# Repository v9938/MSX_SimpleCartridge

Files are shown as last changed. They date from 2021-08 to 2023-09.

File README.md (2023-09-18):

# MSX用カートリッジ<BR>32/64K Simple ROM Cartridge
ひねりも何も無いFlash ROMを32/64KByteをマッピングしたカートリッジです。  
現在入手可能な部品を使い、最小現のパーツで構成されています。  

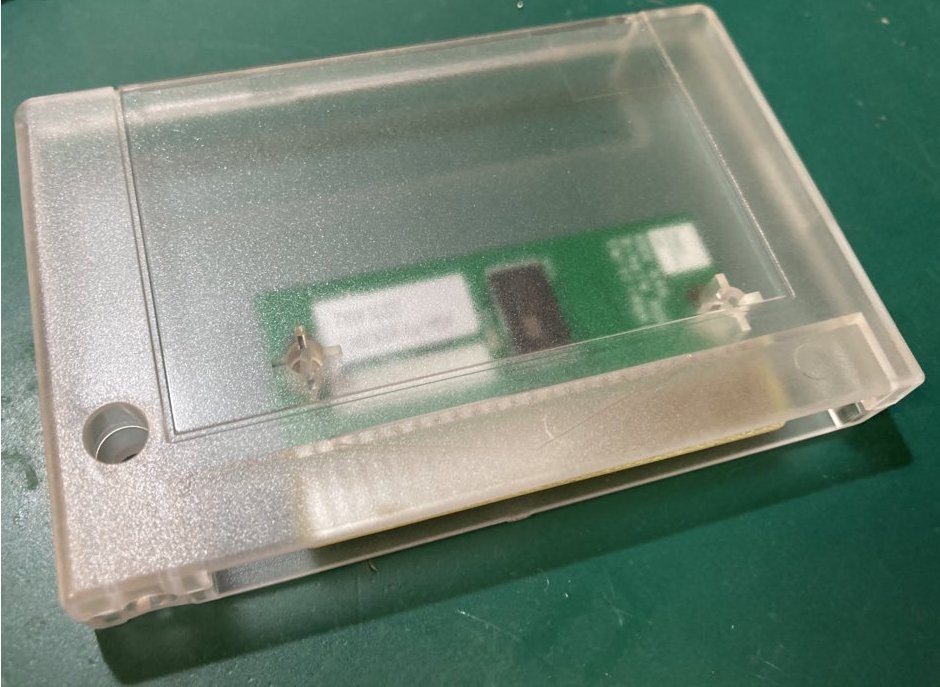
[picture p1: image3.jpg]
Case WithCase

  
SST社の39SF010/020/040との組み合わせで動作確認を行っていますが、  
基板自体はある程度汎用で利用できる様に設計されており、設定変更で他型番のEPROMの利用が可能です。  

なお、本基板および各パーツは、家電のKENちゃんおよびBoothにて頒布しています。  (Boothは不定期に追加)  

## ■ 頒布先
### 家電のKENちゃん
●MSX用カートリッジ64K Simple ROM Cartridge 【SOP版 完成品】  
https://www.kadenken.com/view/item/000000001288  

●シェルケース（廉価版）  
- クリアブラック  
https://www.kadenken.com/view/item/000000001497  
- クリアブルー  
https://www.kadenken.com/view/item/000000001498  
- クリアピンク  
https://www.kadenken.com/view/item/000000001500  
- クリアオレンジ  
https://www.kadenken.com/view/item/000000001499  
- 白  
https://www.kadenken.com/view/item/000000001496  
- 黒  
https://www.kadenken.com/view/item/000000001495  

シェルケース(RGR製)
- 透明  
https://www.kadenken.com/view/item/000000001315  

### Booth
●基板/パーツ/完成品  
-https://ifc.booth.pm/items/3200264
  
●カートリッジケース(RGR製)  
https://ifc.booth.pm/items/3240279

### JLCPCB
●シェルケース（3Dプリント）  
https://3d.jlcpcb.com/3d-models/detail/MX1901-MSX-Cartridge-shell-(KOMAMI-Type)

(2023/8/1追記)  
Microchip社のFlashROMのDIPパーケージ品が想定以上に値上がり&入荷が不安定なため、  
今後はSOP版 完成品のみの供給とさせていただきます。機能的な違いはありません。  
  
DIP版が必要な場合はガーバーファイルが同梱していますので、基板業者に直接注文してください。

## ■ Flashの制御方法
Flashのコントロールアドレス2AAAhは2AAAh・コントロールアドレス5555hは5555hにマッピングされています。  
  
本製品は、SST系のFlashを使用しています。  
CMD体系は、AMD系とほぼ同じなのですが、CMDアドレスが違います。  
また、BUSYの出方などもAMD系と異なるため注意してください。  

```
CMD例：
1. Flash Byte-Program 1st : 0x5555 = 0xAA
2. Flash Byte-Program 2nd : 0x2AAA = 0x55
3. Flash Byte-Program 3rd : 0x5555 = 0xA0
4. Write Data             : 0x0000～0xffff = data
```

参考：  
https://www.microchip.com/wwwproducts/en/SST39SF010A  

## ■ Flash書き込みプログラム
書き込みプログラムとして、simplefw.comを同梱しています。  
いずれかのスロットに当該カードリッジを挿入し、以下コマンドを実行してください。  
```
>simplefw.com [書き込みをしたいROM File]　(/0,4,8)
```
オプションとして下記が使えます  
/0 : ROMファイルを0x0000からのアドレスに書き込みます。  
/4 : ROMファイルを0x4000からのアドレスに書き込みます。  
/8 : ROMファイルを0x8000からのアドレスに書き込みます。  
  
書き込みのエンドアドレスは0xBFFFにしてあります。  
0xC000以降の書き込みが必要な場合は下記部分を変更して再コンパイルしてください。  
（0xFFFFは拡張スロットで使われるため書き込みできません）  
```
		//Parameter Check
		if (addressWrite >= 0xC000){				// 4000-Bfffh Write finsh?
			printf("\nROM size is FULL.");			// Ummm.ROM is FULL
```

スロット切り替えが面倒でBIOS Callで1Byteづつ処理しているので遅いです。ゆるして・・・  
  
ソースコードは、z88dkでコンパイル可能です。コンパイルオプションは下記になります。 
```
zcc +msx -create-app -subtype=msxdos -lmsxbios  main.c -o simplefw.com  
```
## ■ その他のFlash書き込みプログラムについて
HRA!氏作成のwrtsstで書き込み可能な事を確認しています。  
上記プログラムより書き込み速度が速いです。^^;  

●wrtsst
https://github.com/hra1129/MSX_MegaSCC_for_SST39SF040/tree/main/tools/wrtsst  

## ■ Flashで実行してるかを調べる方法
頒布用途で使用する場合、FlashROMのIDコードを読むことで、当カセットで実行しているか調べることが可能です。

TestProgram_ROMVerの下記関数を参照してください。  
(当該関数はROM上で実行することができないことに注意してください。)

```
int chkSimpleROM()
```
## ■ 頒布基板について（～RevCまで)
本製品は安価に頒布するため端子部はハンダメッキになっています。  
通常使用では問題は確認されていませんが、金メッキに比べると中長期的な信頼製や耐久性が劣ります。
あらかじめご了承ください。

頒布基板は組み立てキットの「DIP版」/完成品「SOP版」の2つのVersionがあります。  
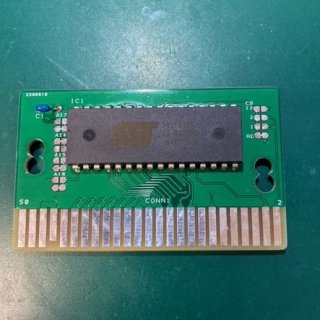
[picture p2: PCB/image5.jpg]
Dip
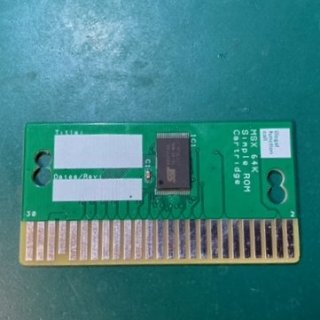
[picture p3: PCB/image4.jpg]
SOP
 

DIP版は32Kマッピング(64Kにも変更可能）SOP版は64Kマッピングの違いがあります。
  
| MSX Slot Address | Flash ROM Address(DIP版) | Flash ROM Address(SOP版) |
|---|---|---|
| 0000-3FFF | 0000-3FFF | 0000-3FFF |
| 4000-7FFF | 4000-7FFF | 4000-7FFF |
| 8000-BFFF | 0000-3FFF(mirror) | 8000-BFFF |
| C000-FFFF | 4000-7FFF(mirror) | C000-FFFF |

DIP版もA15ジャンパの設定変更でSOP版と同じメモリ配置にすることが可能です。

## ■ 頒布基板について（RevD以降)
金メッキ仕上げ品に変更になっているため上記問題はありません。  
メモリマッピングはSOP版と同じメモリ配置になっています。  
  
ガーバファイルを同梱していますので量産や仕様変更をされたい場合に利用ください。  

## ■ 頒布基板について（紫 基板SOP版)
金メッキ仕上げ品に変更しています。上記問題はありません。 
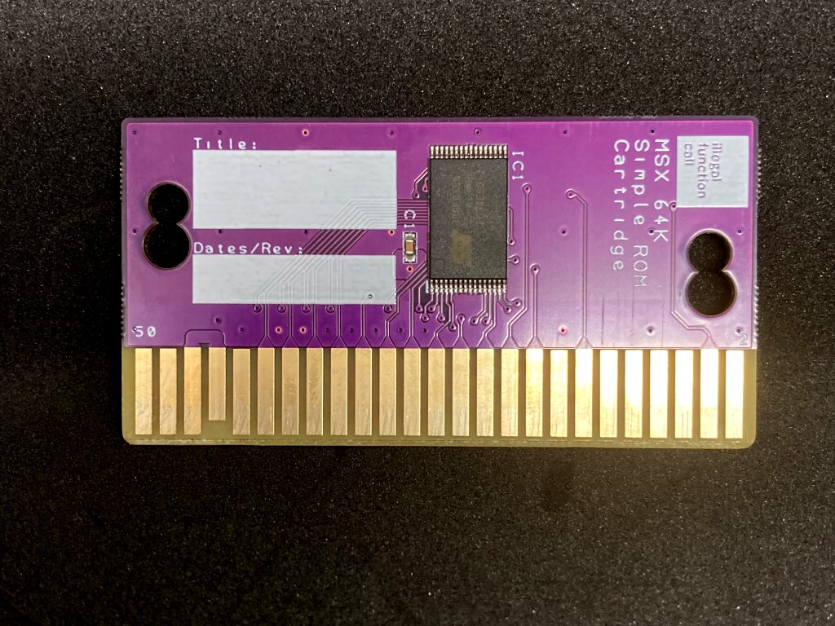
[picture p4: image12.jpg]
SOPPCB


動作確認用にROM IDを確認するソフトが書き込みしてあります。  
初回のみ"e"キーを押して内部のデータを消去してから使用してください。
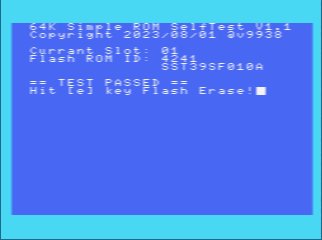
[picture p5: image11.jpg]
TESTDONE TestDone


## ■ ジャンパ設定について
組み立てキットの「DIP版」にはいくつかのジャンパが用意されています。  
設定を変更することにより、アドレス空間のマッピングや違う種類のEPROMを使う事が可能です。  
※Default値は、RevDの設定値(SST39SF010向け)になります、Revにより異なりますので注意ください。  

|ジャンパ  | A17(30Pin) | A14(29Pin) | A15(3Pin) | A18(1Pin) |
|---|---|---|---|---|
| 上側  | +5V  | A14(Default)  | A15(Default) | +5V |
| 下側  | GND(Default)  | A15  | GND  | GND(Default)  |

|CSジャンパ  | ROM ADDRESS |
|---|---|
| RD  | 0x0000-0xFFFF(Default) |
| CS1  | 0x4000-0x7FFF  |
| CS2  | 0x8000-0xBFFF  |
| CS12  | 0x4000-0x7FFF  |

## ■ EPROM設定例
|ジャンパ  | A17(30Pin) | A14(29Pin) | A15(3Pin) | A18(1Pin) |
|---|---|---|---|---|
| 27C32/64/128/256 | 上(+5V)  | 下(A15)  | 下(GND) or 両方カット＋+5Vへのジャンパ | 下(GND) |
| 27C010/040 | 下(GND)  | 下(GND)  | 下(GND)  | 上(+5V) |

### 27C32～256使用時の注意
VPPがGNDでも動作するROMの使用を想定しています。  
VPPに+5Vを要求するタイプの場合、A15に+5Vの選択がないためジャンパが必要です。  
A18上パッド左側が+5Vなので、A15パッドを両方カットし、右側にジャンパしてください。  
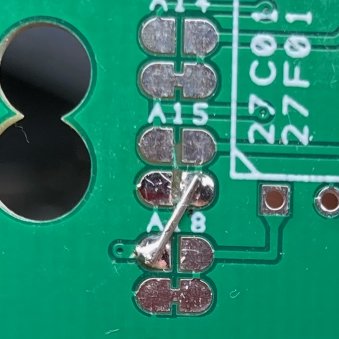
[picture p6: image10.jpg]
VPP対応
  

CSジャンパは、使用したいアドレス領域に合わせてCS1/2/12のいずれかを設定してください。  
27C256を使う場合はアドレスの配置が16KByteで反転するため、A14の設定も必ず変更する様にしてください。

## ■ 基板の組み立て方法
セオリー通り背の低い部品から半田付けしてください。IC1->C1が良いと思います。  
ICソケットを使うとケースに入らなくなるので注意してください。  

## ■ 部品表
| 部品番号 | 部品名 |
|---|---|
| IC1  | Flash ROM SST39SF010/020/040 |
| C1  | コンデンサー0.1uF (104) |
| PCB  | 専用PCB |

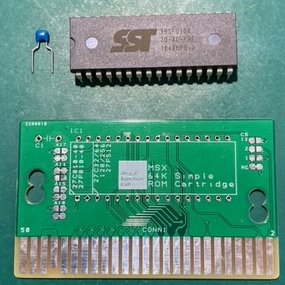
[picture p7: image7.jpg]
Parts


### ■ DIP版 RevBについて
A14 ジャンパのDefault設定が間違っています。下側のパターンをカットし、上側をショートさせてください。  
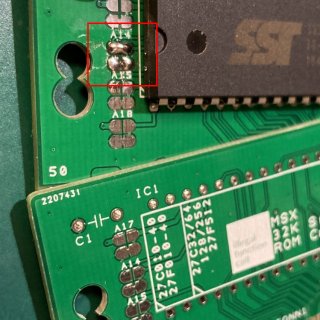
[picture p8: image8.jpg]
J_A14w
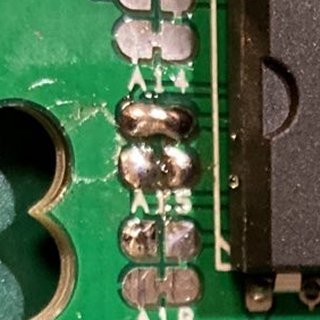
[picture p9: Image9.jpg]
J_A14
 

## ■ カードリッジシェルについて
コナミおよびASCIIタイプのシェルに合わせたネジ穴が空けてあります。  

### 3Dプリント用データ
3Dプリント用のSLTデータを同梱しています。  
固定ネジは2mm x 10mmのタッピングビスを使ってください。  
サンコータイト（＋）Ｐタイプナベに合わせて設計しています。  

JLC PCBさんの3Dプリント Shareデータに登録してあります。材質によりますが、価格は＄4～10ぐらい  
SLA印刷 8111X Resin/Black Resinで寸法調整しています。  

下記URLから注文可能です。  
https://3d.jlcpcb.com/3d-models/detail/MX1901-MSX-Cartridge-shell-(KOMAMI-Type)

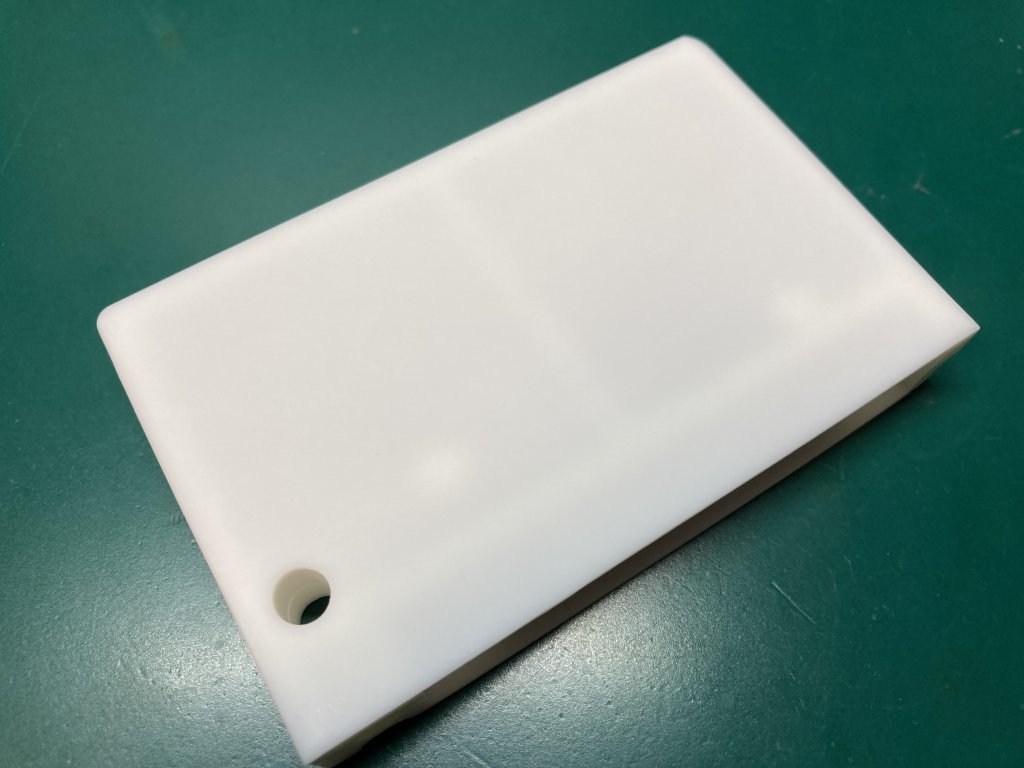
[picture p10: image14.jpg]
shell1
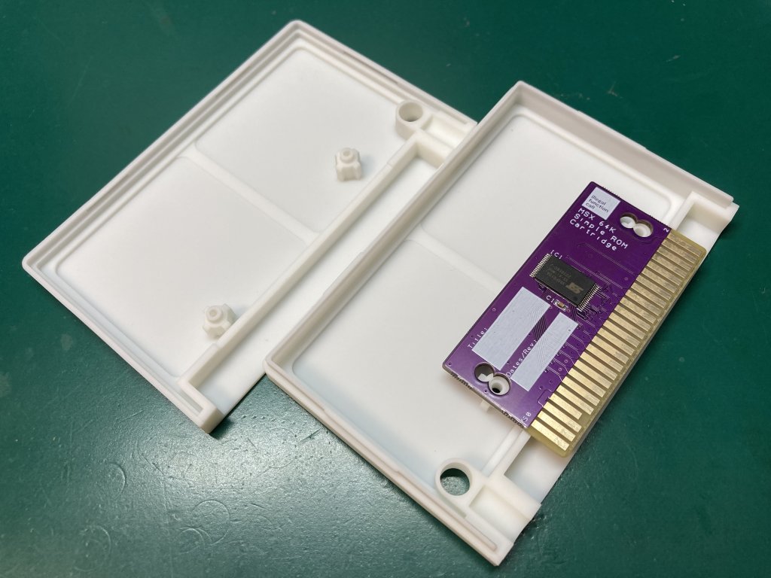
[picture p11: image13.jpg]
shell2

### 成形品のシェル  
RGRさんのTransparent Cartridge Shell for MSX Konami-styleに対応しています。  
https://retrogamerestore.com/store/msx_cart_shell/  
  
Boothや販売委託先でも購入が可能です。
輸入と製造都合で若干の小傷がある場合があります。あらかじめご了承ください。  
国内で購入された場合はRGRさんの付属のネジはちょっとネジ穴を壊しやすいので、当方で用意した樹脂製品向けネジが付属します。  
長さが長い方のネジを使用されることを推奨します。

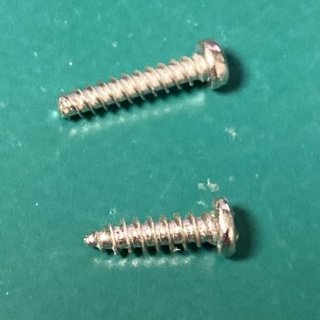
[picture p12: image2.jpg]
negi
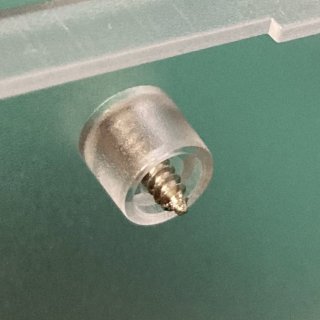
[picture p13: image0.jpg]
negi1
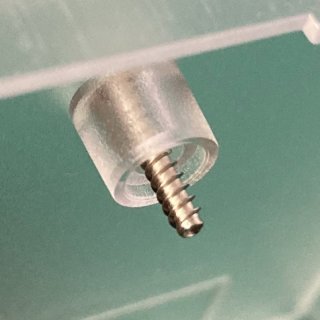
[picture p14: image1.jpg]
negi2
  
  
その他、頒布基板はASCII仕様のいくつかのシェルタイプに対応していますが、  
すべてのタイプには対応していません。ご了承ください。

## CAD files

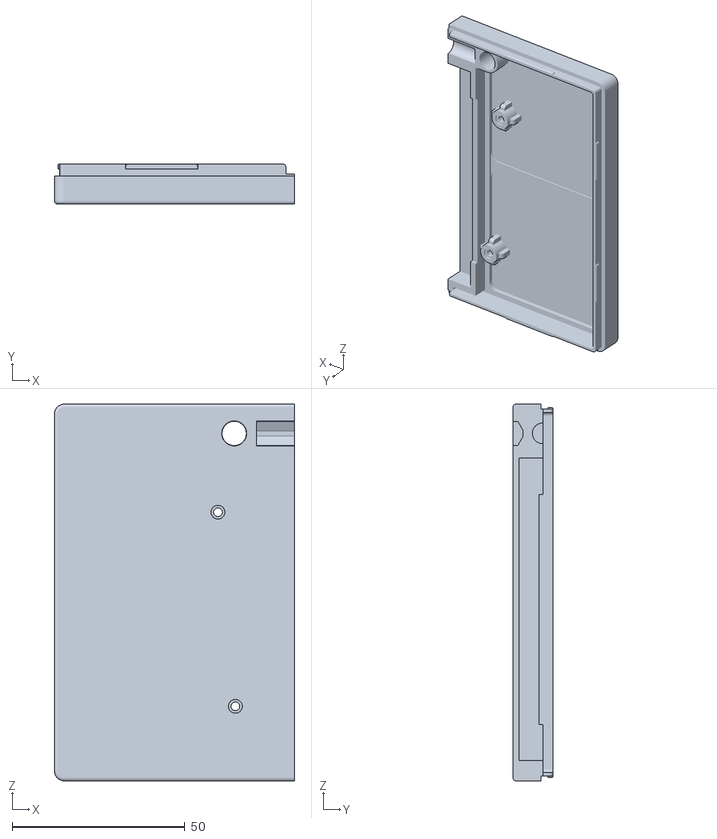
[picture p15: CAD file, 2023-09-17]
Case/RevC_BOTTOM_MSXCART__KONAMIType.stl
69.5 x 11.6 x 109.0

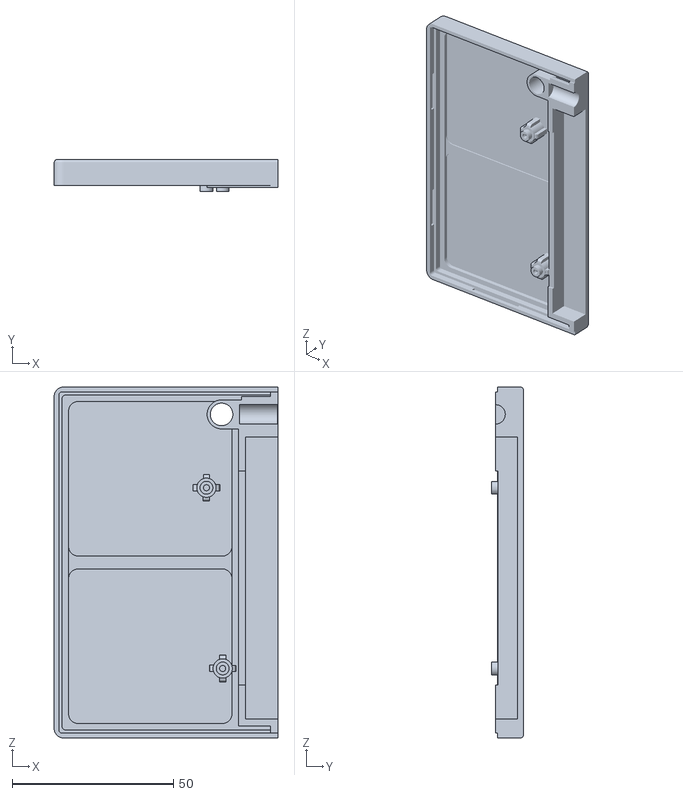
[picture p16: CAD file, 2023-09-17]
Case/RevC_TOP_MSXCART__KONAMIType.stl
69.5 x 9.95 x 109.0

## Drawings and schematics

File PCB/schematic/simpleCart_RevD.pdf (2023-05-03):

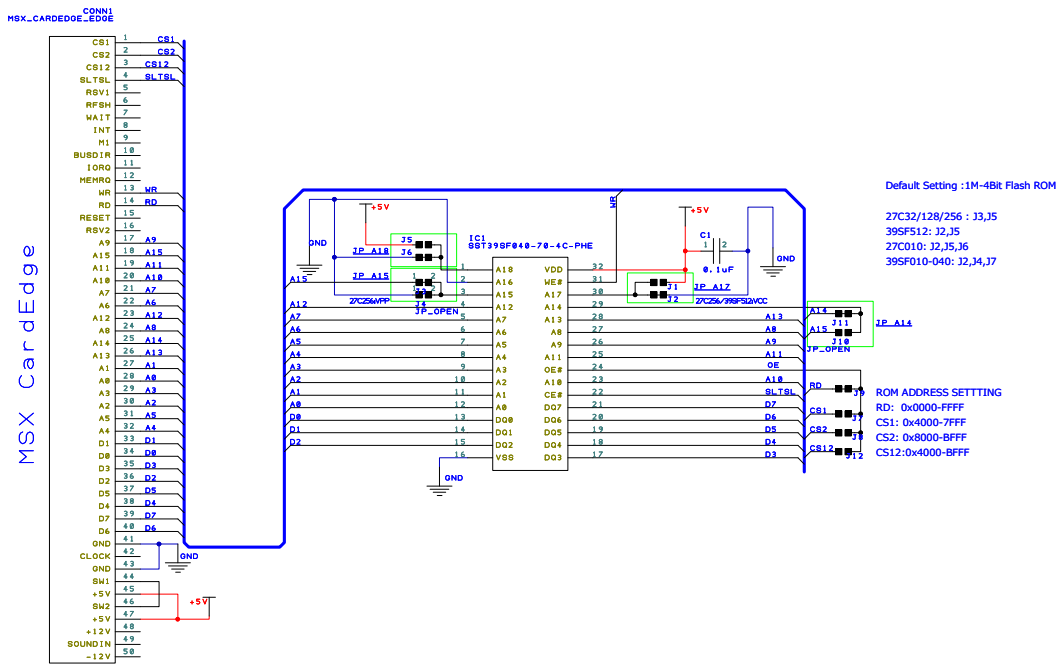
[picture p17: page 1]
MSX Simple ROM Cardrige; Rev D; ROM ADDRESS SETTTING RD: 0x0000-FFFF CS1: 0x4000-7FFF CS2: 0x8000-BFFF CS12:0x4000-BFFF

Default Setting :1M-4Bit Flash ROM

Simple ROM card

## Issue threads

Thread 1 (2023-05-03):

コンデンサー C1 の値が矛盾している？

mikecat, 2023-05-03:
`README.md` の部品表に

> C1 | コンデンサー0.01uF (104)

とありますが、一般的には104は0.1μF、0.01μFは103であり、矛盾しているのではないかという印象があります。

参考

* [コンデンサーの読み方](https://www.jarl.org/Japanese/7_Technical/lib1/konden.htm)
* [コンデンサ容量値・定格電圧の読み方 | Spiceman](https://spiceman.jp/capacitor-value/)
* [抵抗値・コンデンサの読み方｜評価試験用電源なら松定プレシジョン](https://www.matsusada.co.jp/column/resistance-condenser.html)

v9938, 2023-05-03:
104が正しいため修正しました。

Closed 2023-05-03.

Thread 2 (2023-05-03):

「ジャンパ設定について」の表が誤解を招く

mikecat, 2023-05-03:
`README.md` の「ジャンパ設定について」の表において、A14(29Pin) の下側が「GND」となっていますが、
基板の現物 (訳あり品 2021/09 Rev:D) を確認したところ、A14の下側はA15に繋がっていました。
さらに、ここに上がっている回路図 `simpleCart_RevC.pdf` においても、IC1のA14の接続先はA14とA15になっており、GNDは選択肢に無いようです。
「DIP版」というだけでなく、対象のRevを明示したほうがいいと思います。

なお、下の「EPROM設定例」においても「A14(29Pin)」が「下(GND)」となっており、同様の問題があります。

v9938, 2023-05-03:
当該部分の追記およびRevDの回路図を追加しました。

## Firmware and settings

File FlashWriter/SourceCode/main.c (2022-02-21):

/*
	SimpleROM Flash ROM programmer
	Copyright 2021 @V9938
	
	V1.0	2021/07/24	1st version
	V1.1	2022/02/22	Added support for writing to Page3.
*/

#include <stdio.h>
#include<string.h>
#include <msx.h>
#include <sys/ioctl.h>

#define VERSION "V1.1"
#define DATE "2022/02"

#define BUF_SIZE 128

//Global
unsigned char SelectSlot;		//Select Slot number
unsigned char *addressWrite;	//Write pointer
unsigned char eseSlot;			//SimpleROM Slot number
unsigned char maxBank;			//ROM Size
int findId;						//Flash ID


//Assembler SubRoutine
void asmCalls(){
#asm
serupCmd:
	di
    ld a,(_SelectSlot)	;Slot Number
	ld e,0aah			;
    ld hl,05555h		;Flash Address 2nd 0x5555
    call 0014h			;call WRSLT

    ld a,(_SelectSlot)	;Slot Number
	ld e,055h			;
    ld hl,02aaah		;Flash Address 1st 0x2AAA
    jp 0014h			;call WRSLT

#endasm
}
void eraseSimpleROM() __z88dk_fastcall __naked {
#asm
	; Chip-Erase Command 1st
    ; aa-55-80

	call	serupCmd
    ld a,(_SelectSlot)	;Slot Number
	ld e,080h			;
    ld hl,05555h		;Flash Address 2nd 0x5555
    call 0014h			;call WRSLT

	; Chip-Erase Command 2nd
	; aa-55-10
	call	serupCmd
    ld a,(_SelectSlot)	;Slot Number
	ld e,010h			;
    ld hl,05555h		;Flash Address 2nd 0x5555
    call 0014h			;call WRSLT
	ei

    ld hl,0fc9eh		;JIFFY address
	ld a,(hl)			;Load INTCNT
	add 06h				;16.6ms x 6 = 99.6ms
busyWait:
	cp	(hl)			;Check INTCNT
	jr nz,busyWait		;Wait Loop
	ret
sltpush: 
	db		00
extpush: 
	db		00
sltmask: 
	db		00
extmask:
	db		00
#endasm
}
void writeSimpleROMpage3(unsigned char *Address,unsigned char data)
{
#asm
	ld ix,2
	add ix, sp
	ld h, (ix+3)		;address_h
	ld l, (ix+2)		;address_L
	ld e, (ix)			;data
	push de
	push hl
// 
	in a,(0a8h)			;backup PSL
	ld (sltpush),a
	ld a,(0ffffh)
	cpl
	ld (extpush),a
	
    ld a,(_SelectSlot)	;Slot Number
	sla a
	sla a
	sla a
	sla a
	ld b,a
	and 11000000b
	ld c,a				;ext mask
	ld a,b
	sla a
	sla a
	ld b,a				;slt mask
	ld a,(sltpush)
	and 00111111B
	or b
	ld (sltmask),a

	ld a,(extpush)
	and 00111111B
	or c
	ld (extmask),a

;
; Flash Byte-Program
; aa-55-a0

	call	serupCmd
    ld a,(_SelectSlot)	;Slot Number
	ld e,0a0h			;
    ld hl,05555h		;Flash Address 2nd 0x5555
    call 0014h			;call WRSLT

	pop hl
	pop de
	di
	ld a,(sltmask)
	out (0a8h),a
	ld a,(_SelectSlot)
	and 080h
	jr z,datawr
	ld a,(extmask)
	ld (0ffffh),a
datawr:
	ld (hl),e
datawrWait:
	ld a,(hl)
	cp e					; Verify check
;for test
	jr nz,datawrWait			; Wait Byte-Program Time
	
	ld a,(extpush)
	ld (0ffffh),a
	ld a,(sltpush)
	out (0a8h),a

	ei
	ret
#endasm
}
void writeSimpleROM(unsigned char *Address,unsigned char data)
{
#asm
	ld ix,2
	add ix, sp
	ld h, (ix+3)		;address_h
	ld l, (ix+2)		;address_L
	ld e, (ix)			;data
	push de
	push hl
;
; Flash Byte-Program
; aa-55-a0

	call	serupCmd
    ld a,(_SelectSlot)	;Slot Number
	ld e,0a0h			;
    ld hl,05555h		;Flash Address 2nd 0x5555
    call 0014h			;call WRSLT

    ld a,(_SelectSlot)	;Slot Number
	pop hl
	pop de
	push de
	push hl
    call 0014h			;call WRSLT
	pop hl
	pop de
writeWait:	
	push de
	push hl
    ld a,(_SelectSlot)	;Slot Number
    call 000ch			;call RDSLT
	pop hl
	pop de
    cp e					; Verify check
    jr nz,writeWait			; Wait Byte-Program Time
	ei
	ret
#endasm
}

int chkSimpleROM() __z88dk_fastcall __naked {
#asm
	call	serupCmd

    ld a,(_SelectSlot)	;Slot Number
	ld e,090h			;
    ld hl,05555h		;Flash Address 2nd 0x5555
    call 0014h			;call WRSLT

    ld a,(_SelectSlot)	;Slot Number
    ld hl,04000h		;Read Maker ID
    call 000ch			;call RDSLT
    ld b,a
	push bc
    ld a,(_SelectSlot)	;Slot Number
    ld hl,04001h		;Read Read Device ID
    call 000ch			;call RDSLT
	pop bc
    ld c,a
    push bc

	; Reset Command sequence aa-55-f0
	call	serupCmd

    ld a,(_SelectSlot)	;Slot Number
	ld e,0f0h			;
    ld hl,05555h		;Flash Address 2nd 0x5555
    call 0014h			;call WRSLT
	pop hl
	ei
	ret
#endasm
}

void findSimpleROM(void){
	unsigned char i;
	unsigned int chipId;
	
	if ((SelectSlot & 0xf0) == 0x80){
		//Expantion Slot Check
		for (i=0;i<4;i++){
			chipId = chkSimpleROM();
			if ((chipId & 0xff00) == 0xbf00) {		//0xBF SST Maker ID
				eseSlot = SelectSlot;
				findId = chipId;
			}
			SelectSlot = SelectSlot + 4;
		}
	}else{
		//Master Slot Check
		chipId = chkSimpleROM();
		if ((chipId & 0xff00) == 0xbf00) {			//0xBF SST Maker ID
			eseSlot = SelectSlot;
			findId = chipId;
		}
	}
}
	
int main(int argc,char *argv[])
{

	FILE *fp;
	unsigned char ReadData[BUF_SIZE];
	unsigned int  ReadPt,WriteMax;
	unsigned char WriteData;
	int i;
	unsigned char SkipFlag;
	unsigned char EndFlag;
	
	printf("Simple Cartridge Writer %s\n",VERSION);
	printf("Copyrigth %s @v9938\n\n",DATE);

	if (argc<2){
		printf( "simplew [rom files]\n");
		printf( "This program will write the selected file to the flash ROM.\n");
		printf( "Option :\n");
		printf( " /0 : Start address 0x0000\n");
		printf( " /4 : Start address 0x4000 (Defaults)\n");
		printf( " /8 : Start address 0x8000\n");
		return 0;
	}

	addressWrite = (unsigned char *)0x4000;
    for(i=1; i<argc; i++) {
		if (strncmp(argv[i],"/0",2) == 0) 	addressWrite = (unsigned char *)0x0000;
		if (strncmp(argv[i],"/4",2) == 0) 	addressWrite = (unsigned char *)0x4000;
		if (strncmp(argv[i],"/8",2) == 0) 	addressWrite = (unsigned char *)0x8000;
    }
    for(i=1; i<argc; i++) {
		if (strncmp(argv[i],"/",1) != 0) break;
    }
	

	printf("Search Flash ... ");
	eseSlot = 0;
	//Slot 1 Search
	SelectSlot = *((unsigned char *)0xfcc2) | 0x01;		//EXPTBL (SLOT1)
	findSimpleROM();
	//Slot 2 Search
	SelectSlot = *((unsigned char *)0xfcc3) | 0x02;		//EXPTBL (SLOT2)
	findSimpleROM();
	//Slot 3 Search
	SelectSlot = *((unsigned char *)0xfcc4) | 0x03;		//EXPTBL (SLOT3)
	findSimpleROM();
//SelectSlot = 0x01;
//eseSlot = 0x01;
//findId = 0xb5;
	if (eseSlot == 0) {								// Not find SimpleROM
		printf("NOT find\n");
		printf("Bye...\n");
		return -1;
	}else{
		printf("Find!\n");
		printf("\nSlot: %02x",eseSlot);
	}

	//Flash Type Check
	printf("\nFlash Type: ");
	if ((findId & 0x00ff) == 0xb5){
		printf("SST39SF010A\n");
		maxBank = 0xf;
	}else if ((findId & 0x00ff) == 0xb6){
		printf("SST39SF020A\n");
		maxBank = 0x1f;
	}else if ((findId & 0x00ff) == 0xb7){
		printf("SST39SF040A\n");
		maxBank = 0x3f;
	}else{
		printf("Unknown Flash\n");
		printf("Bye...\n");
		return -1;
	}

	//ROM File Open
	fp =fopen(argv[i],"rb");
    if( fp == NULL ){
    	printf( "File can't open... %s\n", argv[1]);
    	return -1;
    }

	//Bank set
	SelectSlot = eseSlot;

	//Flash Erase
	printf("\nFlash Erase ... ");
	eraseSimpleROM();
	printf("Done.");

	//Flash Write
	printf("\nStart address : 0x%04x",addressWrite);
	printf("\n");

	EndFlag = 0;
	while (1){

		fread(ReadData,sizeof ReadData, 1, fp);		//Read Buffer

		if (feof(fp) != NULL) break;				//File End ?
		if (ferror(fp) != NULL) {					//EIO Error?
			printf("File IO Error!\n");
			fclose(fp);
			return -1;
		}

		//Parameter Check
		if (EndFlag == 1){				// 4000-Bfffh Write finsh?
			break;									//
		}else{
//			printf("\x1e\x0dFlash Write ... 0x%04x\n",addressWrite);
			printf("\x0dFlash Write ... 0x%04x-%04x",addressWrite,addressWrite+BUF_SIZE-1);
			for (ReadPt = 0;ReadPt<BUF_SIZE;ReadPt++){
				SkipFlag = 0;
				if (addressWrite == 0xffff) EndFlag = 1;
				//Memoryed IO address (expansion slots address)
				if ((addressWrite >= 0xffff) & (addressWrite <= 0xffff)) 	SkipFlag = 1;
				if((SkipFlag == 0) & (EndFlag == 0)){
					WriteData = *(ReadData+ReadPt);
					if (addressWrite >= 0xc000){
						writeSimpleROMpage3(addressWrite,WriteData);	//Write Data
					}else{
						writeSimpleROM(addressWrite,WriteData);	//Write Data
					}
				}
				addressWrite ++;
			}
		}
	}
	fclose(fp);
	printf("\n\nDone. Thank you using!\n");
	return 0;

}

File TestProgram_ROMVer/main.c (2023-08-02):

#include <stdio.h>
#include <msx.h>
#include <sys/ioctl.h>


//#include <msx/gfx.h>

unsigned char SelectSlot;		//Select Slot number
unsigned char transbuf[0x80];	//Page3 program temp area


// Jump Table
void do_eraseFlash() __z88dk_fastcall __naked  {
#asm
    jp _transbuf
#endasm
}

int do_chkSimpleROM() __z88dk_fastcall __naked {
#asm
    jp _transbuf+_chkSimpleROM - _eraseFlash
#endasm
}

// Page3 Transfer routine ////////////////////////////////////////////
void eraseFlash() __z88dk_fastcall __naked {
#asm
	di
	ld de,05555h			; CHIP ERASE ======================
	ld a,0aah				; Flash Address 1nd 0x5555 = 0xAA
    ld (de),a				; 
    
    ld a,(_SelectSlot)		; Slot Number
	ld e,055h				;
    ld hl,02aaah			; Flash Address 2nd 0x2AAA = 0x55
    call 0014h				; call WRSLT (Page0 usually use in MSXBIOS)

	ld de,05555h			; Flash Address 3rd 0x5555 = 0x80
	ld a,080h				;
    ld (de),a				;

	ld a,0aah				; Flash Address 4th 0x5555 = 0xaa
    ld (de),a				; 
    
    ld a,(_SelectSlot)	;Slot Number
	ld e,055h				; 
    ld hl,02aaah			; Flash Address 5th 0x2AAA = 0x55
    call 0014h				; call WRSLT

	ld de,05555h			; Flash Address 6th 0x5555 = 0x10
	ld a,010h				;
    ld (de),a				; do chip erase with busy
loop:
    jr loop					; Stack (It should be waiting erase busy)
#endasm
}
int chkSimpleROM() __z88dk_fastcall __naked {
#asm

	di
	ld de,05555h			; SOFT ID READ ======================
	ld a,0aah				;
    ld (de),a				; Flash Address 1st 0x5555 = 0xAA

    ld a,(_SelectSlot)		; Slot Number
	ld e,055h				;
    ld hl,02aaah			; Flash Address 2nd 0x2AAA = 0x55
    call 0014h				; call WRSLT (Page0 usually use in MSXBIOS)

	ld de,05555h
	ld a,090h				; Flash Address 3rd 0x5555 = 0x90
    ld (de),a				; 

	ld bc,(04000h)			; Read SOFT ID (Any Addresss)
	push bc					; 

	ld a,0aah				; Reset Command ====================
    ld (de),a				; Flash Address 1st 0x5555 = 0xaa

    ld a,(_SelectSlot)		; Slot Number
	ld e,055h				;
    ld hl,02aaah			; Flash Address 2nd 0x2AAA = 0x55
    call 0014h				; call WRSLT

	ld de,05555h			;
	ld a,0f0h				; Flash Address 3rd 0x5555 = 0xf0
    ld (de),a				; Chip Resert

	pop hl					; Return SOFT ID
	ei

	ret
#endasm
}
// End of Page3 Transfer ////////////////////////////////////////////

// Don't Move it ////////////////////////////////////////////////////
void copy_eraseFlash(){
	unsigned char *src;
	unsigned char *des;
	unsigned char size;
	
	// It should be coded using LDIR :-)
	src = (unsigned char *) eraseFlash;
	des = (unsigned char *) transbuf;
	size = copy_eraseFlash - eraseFlash;
	while (size != 0){
		*(des) = *(src);
		size--;
		src++;
		des++;
	}
}


int chget(){
#asm
	call 009fh				; CHGET
    ld l,a					; Return SLT
    ld h,0					
#endasm
}

void set_color(char forcolor, char bakcolor, char bdrcolor)
{
#asm
    ld   ix,0
    add  ix,sp
    ld   a,(ix+2)			; BDRCLR
    ld   (0f3ebh),a
    ld   a,(ix+4)			; BAKCLR
    ld   (0f3eah),a
    ld   a,(ix+6)			; FORCLR
    ld   (0f3e9h),a
	call 0062h				; CHGCLR
;   ld   ix,0111h			; CHGCLR
;   call 015fh				; EXTROM
#endasm
}
void set_text() __z88dk_fastcall __naked {
#asm
    call 00D2h				; TOTEXT
	call 00C3h
#endasm
}
void set_screen(unsigned char *p) __z88dk_fastcall __naked {
#asm
    ld a,(hl)
    jp 005fh				; CHGMOD 
#endasm
}

int get_myslot() __z88dk_fastcall __naked {
#asm
	push hl
	call 0138h				; RSLREG read primary slot #
	rrca					; move it to bit 0,1 of [Acc]
	rrca
	and	00000011b
	ld	c,a
	ld	b,0
	ld	hl,0FCC1H			; EXPTBL see if this slot is expanded or not
	add	hl,bc
	ld	c,a					; save primary slot #
	ld	a,(hl)				; get the slot is expanded or not
	and	80h
	or	c					; set MSB if so
	ld	c,a					; save it to [C]
	inc hl					; Point to SLTTBL entry
	inc	hl
	inc	hl
	inc	hl
	ld	a,(hl)				; Get what  is  currently  output
							; to expansion   slot    register
	and	00001100b
	or	c					; Finaly form slot address
	pop hl
    ld l,a					; Return SLT
    ld h,0			
	push hl
	ld	h,80h
	call	0024h			; ENASLT enable page 2
	pop hl
	ret
#endasm
}

	
	
void main()
{
	int mySlot;											// My Slot number
	int findId;											// Flash ID
	
	set_text();											// Screen Init & Setting 
	set_color(15,5,7);									// Set Color
	mySlot = get_myslot();								// Get My Slot number 
	if (mySlot < 0x80) mySlot = mySlot & 0x03;			// Slot Mask

	SelectSlot = (unsigned char) mySlot;				// Set Slot number for Asm work
	copy_eraseFlash();									// Program Transfer to Page3 RAM (Need 16K RAM)
	
	printf("64K Simple ROM SelfTest V1.1\n");			// Display Copyright
	printf("Copyright 2023/08/01 @v9938\n\n");
	printf("Currant Slot: %02x\n",SelectSlot);

	findId = do_chkSimpleROM();							// Search & Get Flash ID (jump page3 copy code)
	printf("Flash ROM ID: %04x \n              ",findId);
	
	if (findId == 0xb5bf) printf("SST39SF010A\n");		// Check Flash & Maker ID
	else if (findId == 0xb6bf) printf("SST39SF020A\n"); // Flash ID B5/B6/B7 = 010/020/040
	else if (findId == 0xb7bf) printf("SST39SF040A\n"); // Maker ID BD       = SST(Microchip)
	else {
		printf("UNKNOWN\n");							// Test Failed
		printf("\n!! TEST FAILED !!\n");
		printf("Please Reset/Power off.\n");
		while (1);
	}
	
	printf("\n== TEST PASSED ==");
	printf("\nHit [e] key Flash Erase!");

	while (chget()!='e');								// Wait input "e" key

	printf("\nFlash Erased...Done.\n");
	printf("Please Reset/Power off.\n");
	do_eraseFlash();									// Erase Flash (jump page3 copy code)
}

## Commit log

2021-08-30 1st Release
    First release version
    [simpleCart - Bottom Copper (Resist).gbr, simpleCart - Bottom Copper.gbr, simpleCart - Drill Data - [Through Hole].drl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]
2022-02-21 Fixed program hang when using the expansion slot.
    The page3 read/write function did not support to expansion slots.
    [main.c]
2023-05-03 Fixed TYPO & Add information PCB RevD
    RevD PCBの情報を追加、パーツリストのTypoを修正しました
2023-08-02 Added new PCB information
    新ロット基板（紫）の情報を追記しました。
2023-09-17 Add SLT Shell Data
    3Dプリント用のシェルデータを追加しました。
    [RevC_BOTTOM_MSXCART__KONAMIType.stl, RevC_TOP_MSXCART__KONAMIType.stl]
2023-09-18 Update README.md
    3Dプリントデータの情報をUpdate
